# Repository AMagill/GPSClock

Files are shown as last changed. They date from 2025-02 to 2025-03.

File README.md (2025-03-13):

An unnecessarily precise clock, just because I felt like making one.
- Synchronizes time from GPS
- Updates at 1000Hz for true millisecond display
- Zero flicker display, with no PWM or multiplexing
- Configured with a web page via Bluetooth Low Energy

Folders:
- **CAD**\
CAD models (Fusion 360), gerbers, 3D printable parts (.3mf), schematics, and PCB layouts
- **docs**\
Configuration web page, which is published to https://amagill.github.io/GPSClock/.  (Only works with Chromium-based browsers, unfortunately.)
- **Logic_TLC5952**\
A simple high level analyzer for Saleae Logic to interpret data for the TLC5952.

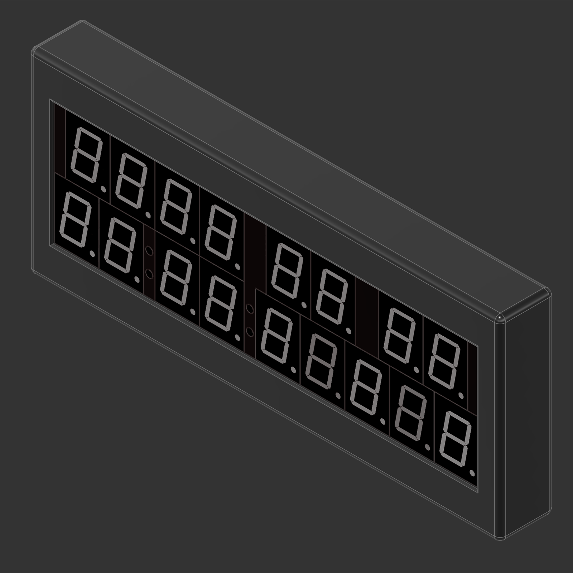
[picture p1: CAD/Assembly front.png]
Front view

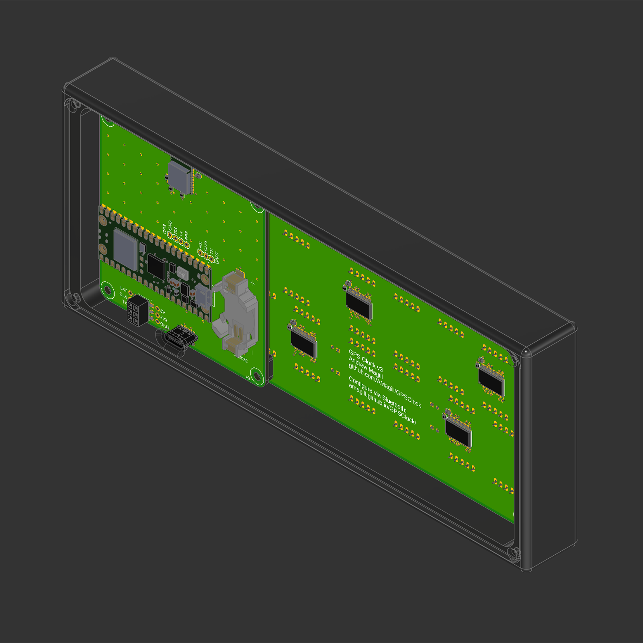
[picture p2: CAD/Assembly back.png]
Back view


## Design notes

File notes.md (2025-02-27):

Pico W
======
https://www.raspberrypi.com/documentation/pico-sdk/
https://github.com/raspberrypi/pico-examples
https://datasheets.raspberrypi.com/pico/raspberry-pi-pico-c-sdk.pdf
3V3 recommended limit 300mA

GPS
===
uBlox CAM-M8Q-0
https://www.digikey.com/en/products/detail/u-blox/CAM-M8Q-0/6150646
https://content.u-blox.com/sites/default/files/CAM-M8-FW3_DataSheet_%28UBX-15031574%29.pdf

Display
=======
TLC5952 LED driver
https://www.digikey.com/en/products/detail/texas-instruments/TLC5952DAP/2078405
https://www.ti.com/lit/ds/symlink/tlc5952.pdf
24 channels, 1 bit per channel
3 groups, 7-bit dimming per group
35MHz data rate
Connects to cathodes, so get common-anode digits.
$2.68

YYYY MM DD    8 digits
HH:MM:SSsss   9 digits + 2 colons

24 channels/driver / 8 channels/digit = 3 digits/driver
17 digits / 3 digits/driver = 5+(16/24) drivers

KW1-801AVB 7-segment LEDs
https://www.digikey.com/en/products/detail/luckylight/KW1-801AVB/22521896
$0.30 0.80" digits!  (50 pack, marketplace, 15-day lead)

Bluetooth
=========
https://bluekitchen-gmbh.com/btstack/v1.0/profiles/#gatt-generic-attribute-profile
https://github.dev/raspberrypi/pico-examples/blob/master/pico_w/bt/standalone/server.c

https://github.dev/bluekitchen/btstack/blob/master/example/le_streamer_client.c

https://github.dev/loginov-rocks/Web-Bluetooth-Terminal
https://loginov-rocks.github.io/Web-Bluetooth-Terminal/

https://developer.mozilla.org/en-US/docs/Web/API/Bluetooth/requestDevice

Flash
=====
https://www.makermatrix.com/blog/read-and-write-data-with-the-pi-pico-onboard-flash/
https://kevinboone.me/picoflash.html

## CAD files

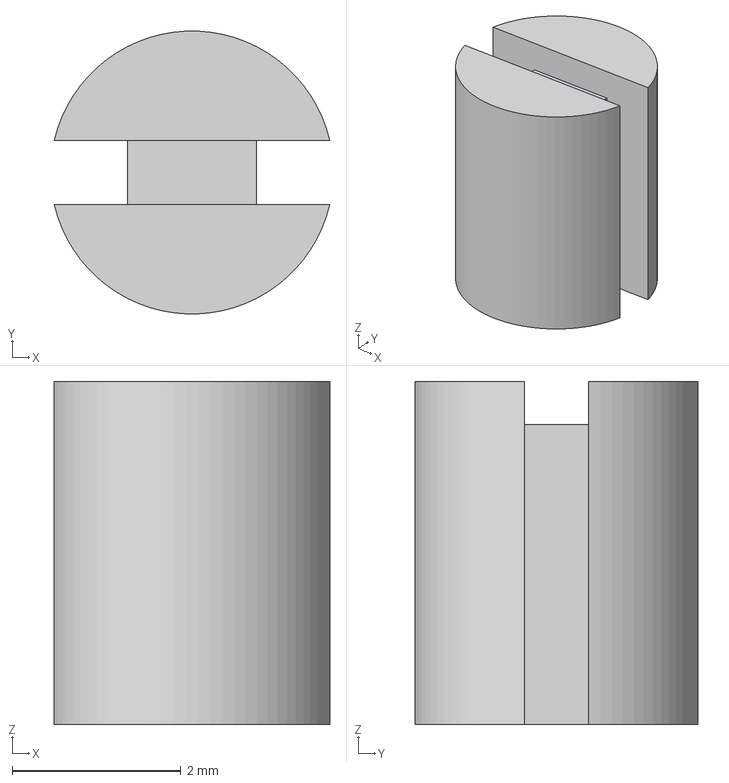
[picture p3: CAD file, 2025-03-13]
CAD/LED spacer.3mf
3.27 x 3.35 x 4.06 mm

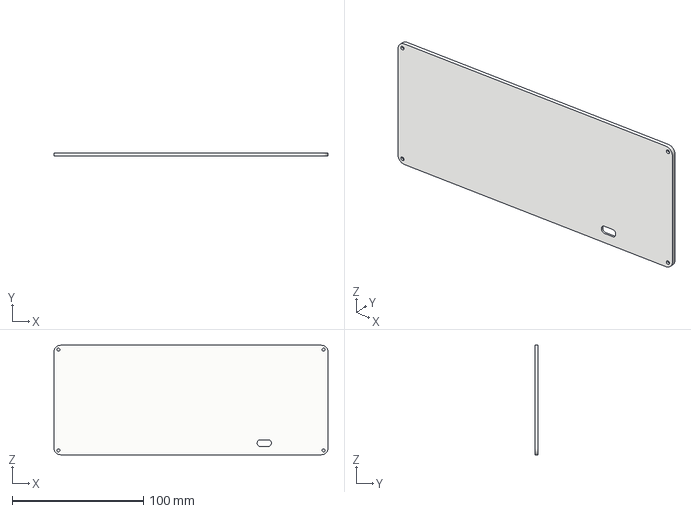
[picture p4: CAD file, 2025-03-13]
CAD/Back cover v14.3mf
209.0 x 2.54 x 83.6 mm

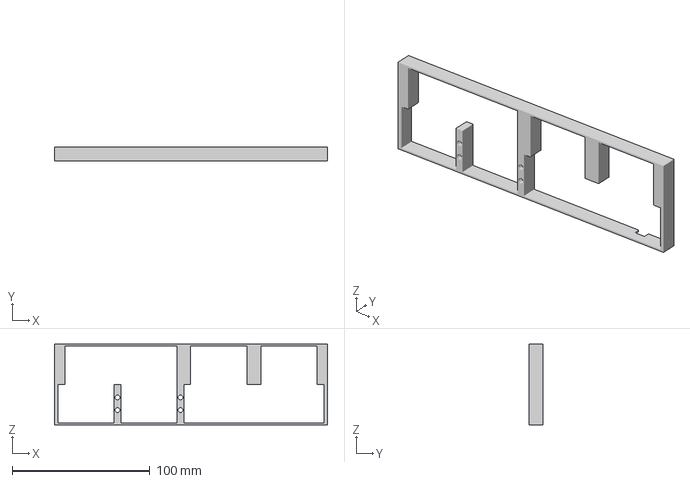
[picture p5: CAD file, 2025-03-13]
CAD/Frame v15.3mf
198.1 x 10.0 x 58.7 mm

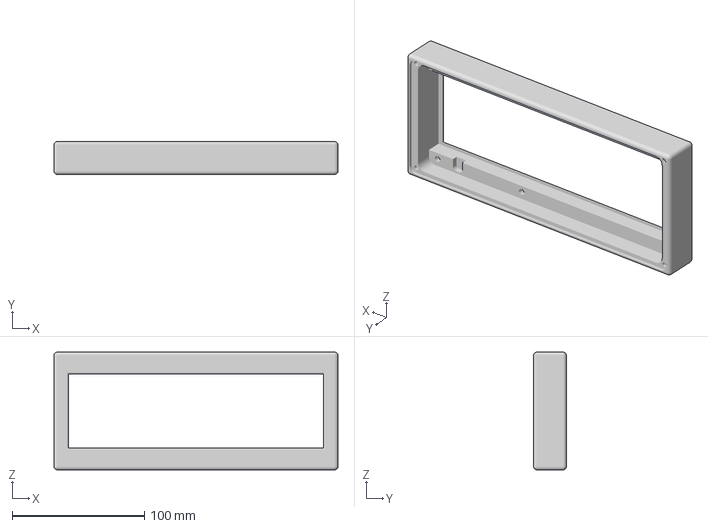
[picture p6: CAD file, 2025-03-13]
CAD/Case v16.3mf
214.8 x 24.9 x 89.2 mm

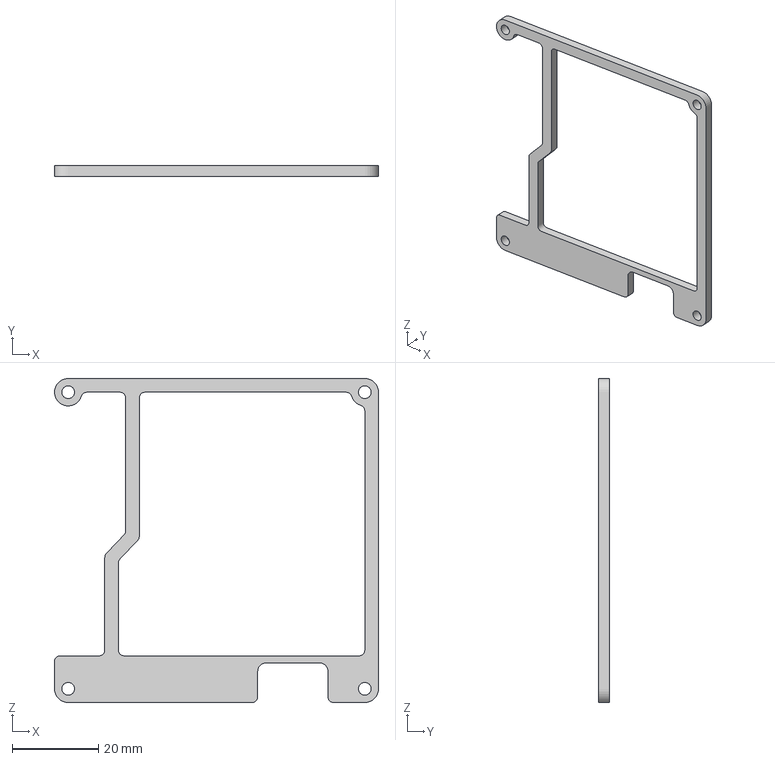
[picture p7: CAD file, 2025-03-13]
CAD/Spacer.3mf
74.9 x 2.54 x 74.9 mm

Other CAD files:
CAD/LED spacer v2.f3d

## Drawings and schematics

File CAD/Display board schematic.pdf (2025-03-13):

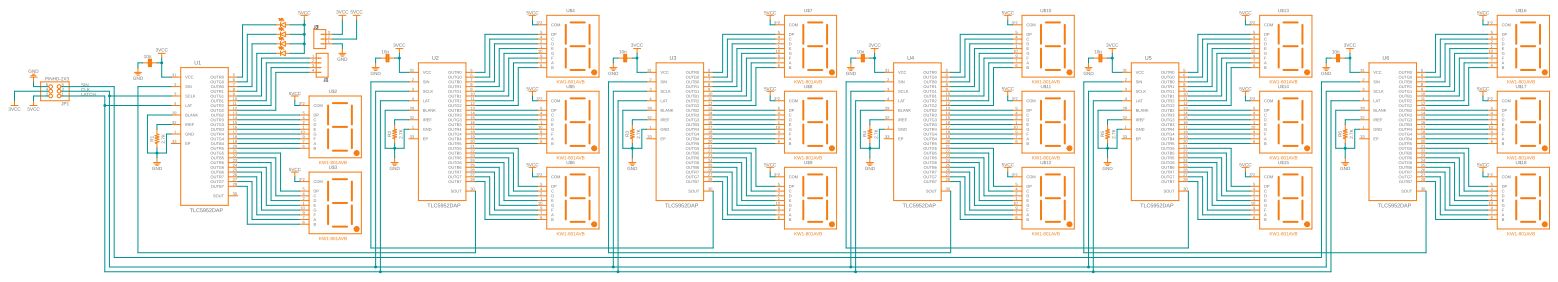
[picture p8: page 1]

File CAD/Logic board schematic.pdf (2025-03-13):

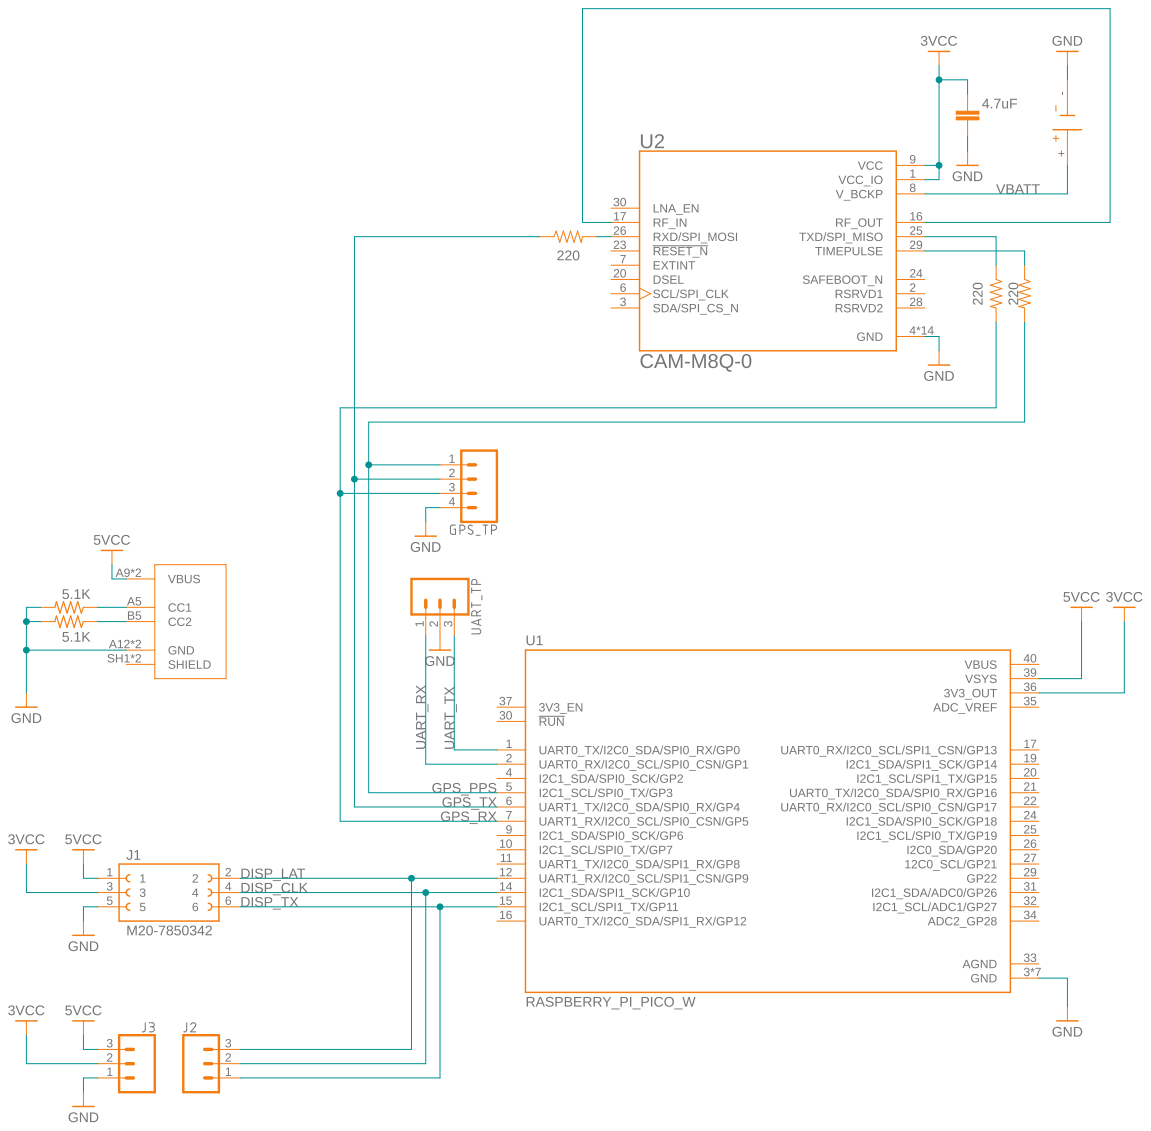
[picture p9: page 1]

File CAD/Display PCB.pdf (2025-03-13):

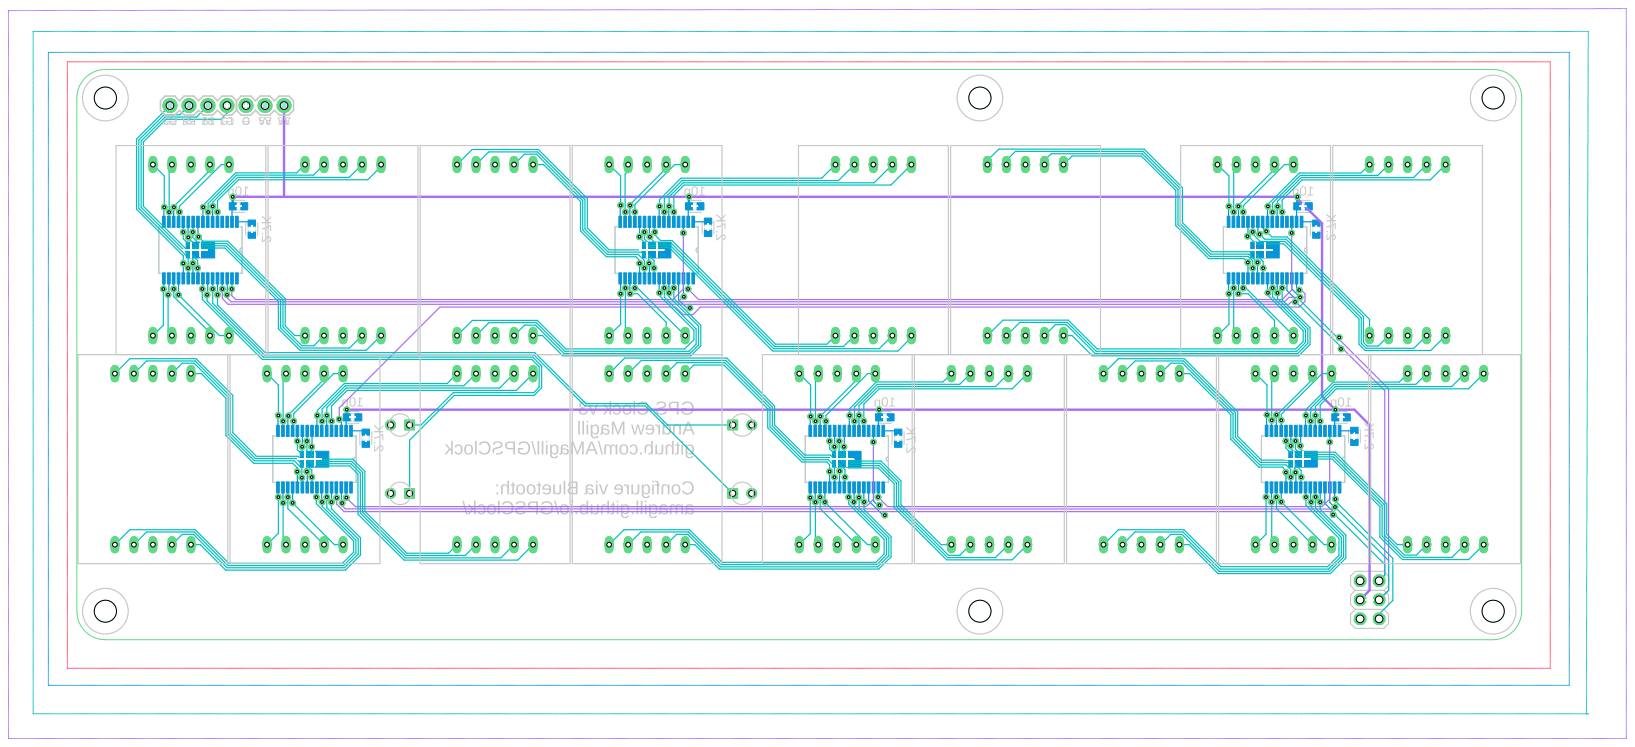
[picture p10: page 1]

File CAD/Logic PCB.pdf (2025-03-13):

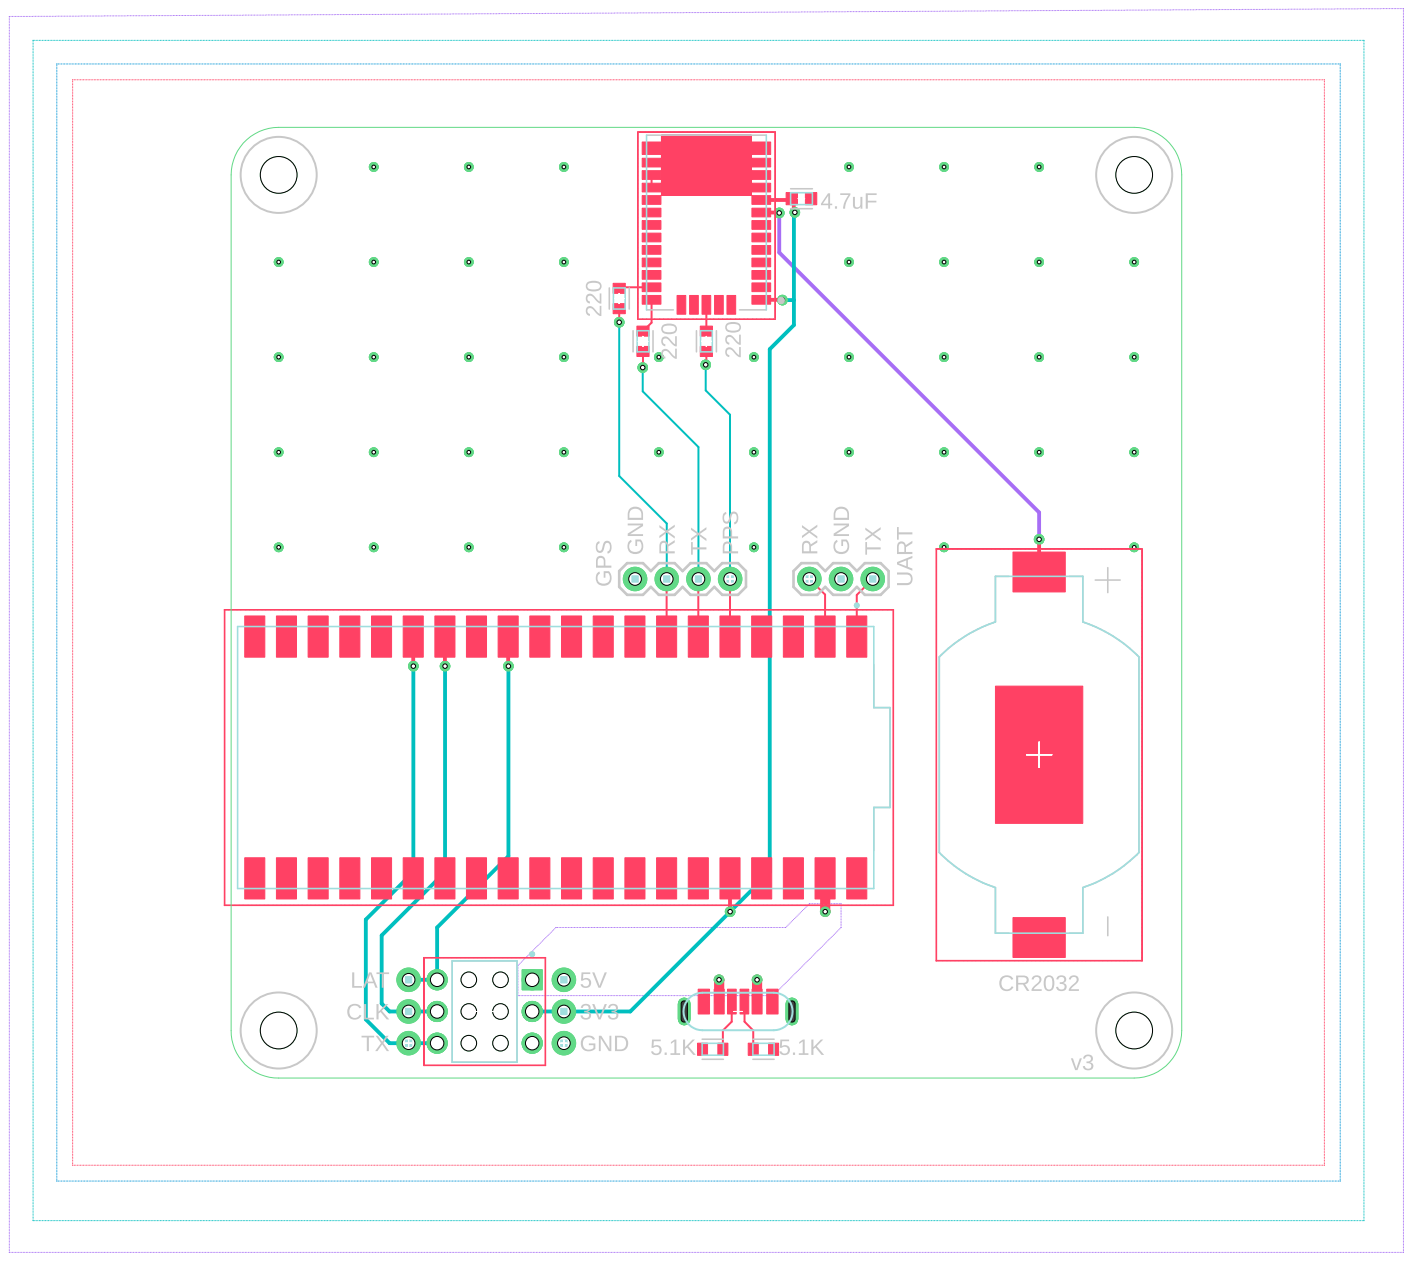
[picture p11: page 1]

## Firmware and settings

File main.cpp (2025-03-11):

#include <stdio.h>
#include "pico/stdlib.h"
#include "hardware/i2c.h"
#include "hardware/flash.h"
#include "gps.hpp"
#include "display.hpp"
#include "ble.hpp"
#include "config.hpp"
#include "time.hpp"

#define GPS_PPS_PIN 3

using namespace std::chrono_literals;

Config config;
uint64_t last_ble_tick = 0;

static void gpio_isr(uint gpio, uint32_t event_mask)
{
	if (gpio == GPS_PPS_PIN)
		gps_on_pps();
}

static void ble_command(BLECommand command)
{
	switch (command)
	{
	case BLECommand::SAVE_SETTINGS:
		config_write_to_flash(config);
		break;
	}
}

int64_t do_every_ms(alarm_id_t id, void *user_data)
{
	// Latch the display state we prepped last time
	disp_latch();

	// Get the time from GPS
	uint64_t clock_offset_us = gps_get_clock_offset_us();
	uint32_t time_acc = gps_get_time_accuracy_ns();

	using namespace std::chrono;
	uint64_t hw_time = to_us_since_boot(get_absolute_time());
	Time_us time_us = Time_us(microseconds(clock_offset_us)) + microseconds(hw_time);

	if (clock_offset_us > 0)
		time_us += config.time_zone * 1h;
	// We're setting up for the next millisecond, so we can just latch it when it's time to display
	time_us += 1000us;
	Time_Parts time = time_split(time_us);

	// Update the display for the next millisecond
	disp_clear();
	disp_set_brightness(config.brightness);
	disp_set_colons(true);

	if (clock_offset_us > 0)
	{
		disp_set_num(1, time.year  / 1000 % 10, false);
		disp_set_num(2, time.year  /  100 % 10, false);
		disp_set_num(3, time.year  /   10 % 10, false);
		disp_set_num(4, time.year         % 10, false);
		disp_set_num(5, time.month /   10 % 10, false);
		disp_set_num(6, time.month        % 10, false);
		disp_set_num(7, time.day   /   10 % 10, false);
		disp_set_num(8, time.day          % 10, false);
	}

	disp_set_num( 9, time.hour   / 10 % 10, false);
	disp_set_num(10, time.hour        % 10, false);
	disp_set_num(11, time.minute / 10 % 10, false);
	disp_set_num(12, time.minute      % 10, false);
	disp_set_num(13, time.second / 10 % 10, false);
	disp_set_num(14, time.second      % 10, true);

	// Degrade display resolution as quality decreases
	if (clock_offset_us == 0 || time_acc < 100'000'000)  // 100ms
		disp_set_num(15, time.millisecond / 100 % 10, false);

	if (clock_offset_us == 0 || time_acc < 10'000'000)  // 10ms
		disp_set_num(16, time.millisecond /  10 % 10, false);
	
	if (clock_offset_us == 0 || time_acc < 1'000'000)  // 1ms
		disp_set_num(17, time.millisecond       % 10, false);

	// Send the display data.  Latches brightness, but not state
	disp_send(false);

	// Send the time to BLE every second
	if (hw_time - last_ble_tick > 1'000'000)
	{
		last_ble_tick = hw_time;
		ble_tick_time(time, time_acc);
	}

	// Schedule the next update
	int64_t us_to_next_ms = 1000 - (time_us.time_since_epoch() % 1ms).count();
	// It takes ~640us to send the display data, so make sure the next one doesn't interrupt
	if (us_to_next_ms < 800)
		us_to_next_ms += 1000;
	return us_to_next_ms;
}

int main()
{
	stdio_init_all();

	// Do early to keep TX glitch small
	gps_init_io(uart1, 9600, 5, 4);

	// Get the screen blanked
	disp_init(pio0, 11, 10, 9);
	disp_set_brightness(0);
	disp_send(true);

	// Load config from flash
	config_read_from_flash(config);

	// This can take almost a second!
	ble_init();
	ble_set_command_cb(ble_command);

	// Send init commands to GPS now that it's had plenty of time to start up
	gps_init_comms();

	// Set up the PPS pin
	gpio_set_irq_callback(gpio_isr);
	gpio_set_irq_enabled(GPS_PPS_PIN, GPIO_IRQ_EDGE_RISE, true);
	irq_set_enabled(IO_IRQ_BANK0, true);

	// Startup screen
	disp_set_brightness(config.brightness);
	disp_set_colons(true);
	for (int i = 1; i < 18; i++)
		disp_set_num(i, 8, true);
	disp_send(true);
	sleep_ms(500);

	disp_clear();
	disp_set_brightness(config.brightness);
	{
		uint8_t id = ble_get_id();
		disp_set_num(7, id >> 4,   false);
		disp_set_num(8, id & 0x0f, false);
	}
	disp_send(true);
	sleep_ms(1000);

	// Set up the display refresh timer
	alarm_pool_init_default();
	add_alarm_in_us(1000, do_every_ms, nullptr, true);

	while (true)
	{
		sleep_ms(1000);
	}
}

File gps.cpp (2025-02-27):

#include "gps.hpp"
#include "hardware/uart.h"
#include <charconv>
#include <chrono>
#include <cstring>

static uart_inst_t* uart;
static std::array<uint8_t, 32> rx_buf;  // Needs to be at least as big as the largest message we expect
static uint         rx_buf_pos         = rx_buf.size();  // Start in overrun state
static uint64_t     clock_offset_us    = 0;
static uint64_t     last_pps_time_us   = 0;
static uint64_t     last_msg_time_us   = 0;
static int          last_correction_us = 0;
static uint32_t     time_accuracy         = 0xFFFFFFFF;

static std::pair<uint8_t, uint8_t> ubx_checksum(std::span<uint8_t> data)
{
	uint8_t ck_a = 0, ck_b = 0;
	for (uint8_t b : data)
	{
		ck_a += b;
		ck_b += ck_a;
	}
	return {ck_a, ck_b};
}

template <typename T>
T read_bytes(std::span<uint8_t>& data)
{
	T value;
	std::memcpy(&value, data.data(), sizeof(T));
	data = data.subspan(sizeof(T));
	return value;
}

template <typename T>
void skip_bytes(std::span<uint8_t>& data)
{
	data = data.subspan(sizeof(T));
}


static void handle_ubx(std::span<uint8_t> msg)
{
	if (msg.size() < 6)  // Shortest possible message with zero payload
		return;
	
	// First validate the checksum
	auto [ck_a, ck_b] = ubx_checksum(msg.subspan(0, msg.size()-2));
	if (ck_a != msg[msg.size()-2] || ck_b != msg[msg.size()-1])
		return;
	
	// We'll consume the message as we go
	msg = msg.subspan(0, msg.size()-2);

	uint64_t hw_time_us = to_us_since_boot(get_absolute_time());

	uint8_t cls = read_bytes<uint8_t>(msg);
	uint8_t id  = read_bytes<uint8_t>(msg);
	skip_bytes<uint16_t>(msg);  // Length

	// Now handle messages we're interested in.
	if (cls == 0x01 && id == 0x21 && msg.size() == 20)  // UBX-NAV-TIMEUTC
	{
		skip_bytes<uint32_t>(msg);  // iTOW
		time_accuracy  = read_bytes<uint32_t>(msg);
		int32_t  nano  = read_bytes<int32_t>(msg);
		uint16_t dy    = read_bytes<uint16_t>(msg);
		uint8_t  dm    = read_bytes<uint8_t>(msg);
		uint8_t  dd    = read_bytes<uint8_t>(msg);
		uint8_t  th    = read_bytes<uint8_t>(msg);
		uint8_t  tm    = read_bytes<uint8_t>(msg);
		uint8_t  ts    = read_bytes<uint8_t>(msg);
		uint8_t  valid = read_bytes<uint8_t>(msg);

		if (!(valid & 0x04))
		{	// Invalid UTC time
			clock_offset_us = 0;
			return;
		}

		// Assemble the time
		using namespace std::chrono;
		Time_us utc_time  = sys_days{year{dy} / month{dm} / day{dd}} + hours{th} + minutes{tm} + seconds{ts};
		uint64_t old_offset = clock_offset_us;
		last_msg_time_us    = hw_time_us;

		// Check how long it's been since the last PPS pulse
		if (hw_time_us - last_pps_time_us < 1'000'000)
		{	// Less than a second since last PPS.  We're going to ignore the
			// milliseconds in the message, and align the second to the PPS.
			clock_offset_us = utc_time.time_since_epoch().count() - last_pps_time_us;
		}
		else
		{	// More than a second since last PPS.  We'll use the message time.
			utc_time += microseconds(nano / 1000);
			clock_offset_us = utc_time.time_since_epoch().count() - hw_time_us;
		}

		last_correction_us = clock_offset_us - old_offset;
		printf("%+d\n", last_correction_us);
	}
}

static void uart_rx_isr()
{
	while (uart_is_readable(uart))
	{
		char ch = uart_getc(uart);
		
		// We only care about UBX messages. They start with 0xB5, 0x62.
		// Use rx_buf_pos as a sort of state machine, invalidating when the frame looks bad.
		if (rx_buf_pos == 0 && ch != 0xB5)
				continue;
		if (rx_buf_pos == 1 && ch != 0x62)
		{
			rx_buf_pos = 0;
			continue;
		}
		if (rx_buf_pos >= rx_buf.size())
		{	// We've overrun the buffer.  Start over.
			rx_buf_pos = 0;
			continue;
		}

		rx_buf[rx_buf_pos++] = ch;
		if (rx_buf_pos > 6)
		{	// We have enough to check the length
			uint16_t len = rx_buf[4] | (rx_buf[5] << 8);
			if (rx_buf_pos == len + 8)
			{	// We have a complete message
				handle_ubx(std::span(rx_buf.data()+2, len+6));
				rx_buf_pos = 0;
			}
		}
	}
}

void gps_send_ubx(uint8_t cls, uint8_t id, std::initializer_list<uint8_t> payload)
{
	std::vector<uint8_t> buf;
	buf.reserve(8 + payload.size());
	buf.push_back(0xB5);
	buf.push_back(0x62);
	buf.push_back(cls);
	buf.push_back(id);
	uint16_t len = payload.size();
	buf.push_back(len & 0xFF);
	buf.push_back(len >> 8);
	std::copy(payload.begin(), payload.end(), std::back_inserter(buf));

	auto [ck_a, ck_b] = ubx_checksum(std::span(buf.begin()+2, buf.end()));
	buf.push_back(ck_a);
	buf.push_back(ck_b);

	uart_write_blocking(uart, buf.data(), buf.size());
}

void gps_init_io(uart_inst_t* uart, uint baud, uint rx_pin, uint tx_pin)
{
	// Set up the GPS UART
	::uart = uart;
	uart_init(uart, baud);
	gpio_set_function(rx_pin, GPIO_FUNC_UART);
	gpio_set_function(tx_pin, GPIO_FUNC_UART);
	uart_set_hw_flow(uart, false, false);  // No CTS, no RTS
	uart_set_format(uart, 8, 1, UART_PARITY_NONE);
	
	uint gps_uart_irq = UART_IRQ_NUM(uart);
	irq_set_exclusive_handler(gps_uart_irq, uart_rx_isr);
	irq_set_enabled(gps_uart_irq, true);
	uart_set_irq_enables(uart, true, false);
}

void gps_init_comms()
{
	gps_send_ubx(0x06, 0x01, {0xF0, 0x00, 0x00});  // UBX-CFG-MSG: GGA off
	gps_send_ubx(0x06, 0x01, {0xF0, 0x01, 0x00});  // UBX-CFG-MSG: GLL off
	gps_send_ubx(0x06, 0x01, {0xF0, 0x02, 0x00});  // UBX-CFG-MSG: GSA off
	gps_send_ubx(0x06, 0x01, {0xF0, 0x03, 0x00});  // UBX-CFG-MSG: GSV off
	gps_send_ubx(0x06, 0x01, {0xF0, 0x04, 0x00});  // UBX-CFG-MSG: RMC off
	gps_send_ubx(0x06, 0x01, {0xF0, 0x05, 0x00});  // UBX-CFG-MSG: VTG off
	gps_send_ubx(0x06, 0x01, {0x01, 0x21, 0x01});  // UBX-CFG-MSG: UBX-NAV-TIMEUTC 1Hz
	gps_send_ubx(0x06, 0x31, {                     // UBX-CFG-TP5:
			0x00,        // TIMEPULSE                 0
			0x01,        // Message version           1 
			0x00, 0x00,  // Reserved
			0x00, 0x00,  // Antenna cable delay       0 ns
			0x00, 0x00,  // RF group delay            0 ns
			 1, 0, 0, 0, // Frequency                 1 Hz
			 1, 0, 0, 0, // Locked frequency          1 Hz
			10, 0, 0, 0, // Pulse length             10 us
			10, 0, 0, 0, // Locked pulse length      10 us
			 0, 0, 0, 0, // User configurable delay   0 ns
			             // Flags:  (Bits 0-7)
			 1<<0 |      //   Active
			 1<<1 |      //   Locked to GPS time
			 1<<3 |      //   Frequency units Hz
			 1<<4 |      //   Time units us
			 1<<5 |      //   Align to top of second
			 1<<6,       //   Rising edge
			             // Flags:  (Bits 8-15)
			 1<<3,       //   Can lose sync
			 0, 0,       // Flags;  (Bits 16-31 unused)
	});
}

uint64_t gps_get_clock_offset_us()
{
	return clock_offset_us;
}

uint32_t gps_get_time_accuracy_ns()
{
	return time_accuracy;
}

void gps_on_pps()
{
	last_pps_time_us = to_us_since_boot(get_absolute_time());
}

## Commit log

2025-01-10 v1 boards basically working
2025-01-19 Added support for v2 display board
2025-01-20 Broke out time split, renamed h to hpp
    [gps.cpp]
2025-01-22 Added DMA transfer to PIO
2025-02-20 Bringing up v3 PCBs
2025-02-24 Switched to UBX protocol, improved timing.
2025-03-13 Dumped in latest CAD files
    [Back cover v14.3mf, Case v16.3mf, Frame v15.3mf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]
